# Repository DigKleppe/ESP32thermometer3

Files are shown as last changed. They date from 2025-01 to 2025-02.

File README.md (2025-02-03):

# ESP32 4 channel high resolution and accurate NTC thermometer

This project uses a dual slope approach to achive high resolution and accurate resistor measurements with a minimal nr of components.
The ADC of the ESP is not very accurate. 
An simple RC is used in combination with a internal ESP timer and a comparator to measure the RC time.
The comparater output is connected to an (high priority) interrupt input.
The process is simple: 
Charge the capacitor to VCC.
Start the timer, and discharge throuh a known reference resitor.
When the voltage level of the C is lower than the comparator reference the interrupt is fired.
The timer stops an the RC time is read.
The same steps for the NTCs.
The resistorvalues of the NTCs are proportional to the RC times.
The temperarures are calculated.

The hardware is not critical. A Filmcapacitor of 1uF and a reference resitor of 10k is used.
For optimal accuracy the value of the referency resistor must be measured and set in measureTask.h (RREF)
As comparator a LM358 is used. Maybe a real (CMOS) comparator gives even better results. If you don't need 
a very high resolution (now about 0.001 C!) you can ommit the comparator.

When measuring a fixed resistor the maximun noise is about +- 0.002 degrees C, depending of averaging.
The accuracy (-10 - 25 degrees C) is better than 0.02 degrees.
At 50 degrees (lower RC values) the deviation is 0.2 degrees. 

I use Vishay 10k 1% NTCs NTCLE203E3 103SBO.  No problem to use long wires.
To use another NTC you have to provide the parameters in NTC.h.

The nr of NTCs can be more than the 4 used here. Use IOports that don't have internal connections in the ESP.

## Website
A website is embedded to show the results in google charts.
To set the system to your network use ESP touch.

Also some settings are provided. You can set offsets to compensate for difference in NTCs. Typical 0.2 degrees max.
I use a (home made ESP) thermometer with a +- 0.1 degree accurate TMP117 sensor to calibrate.

## Project

The project is made in visual studio code. No arduino , LVGL version 9,  IDF version 5.4.

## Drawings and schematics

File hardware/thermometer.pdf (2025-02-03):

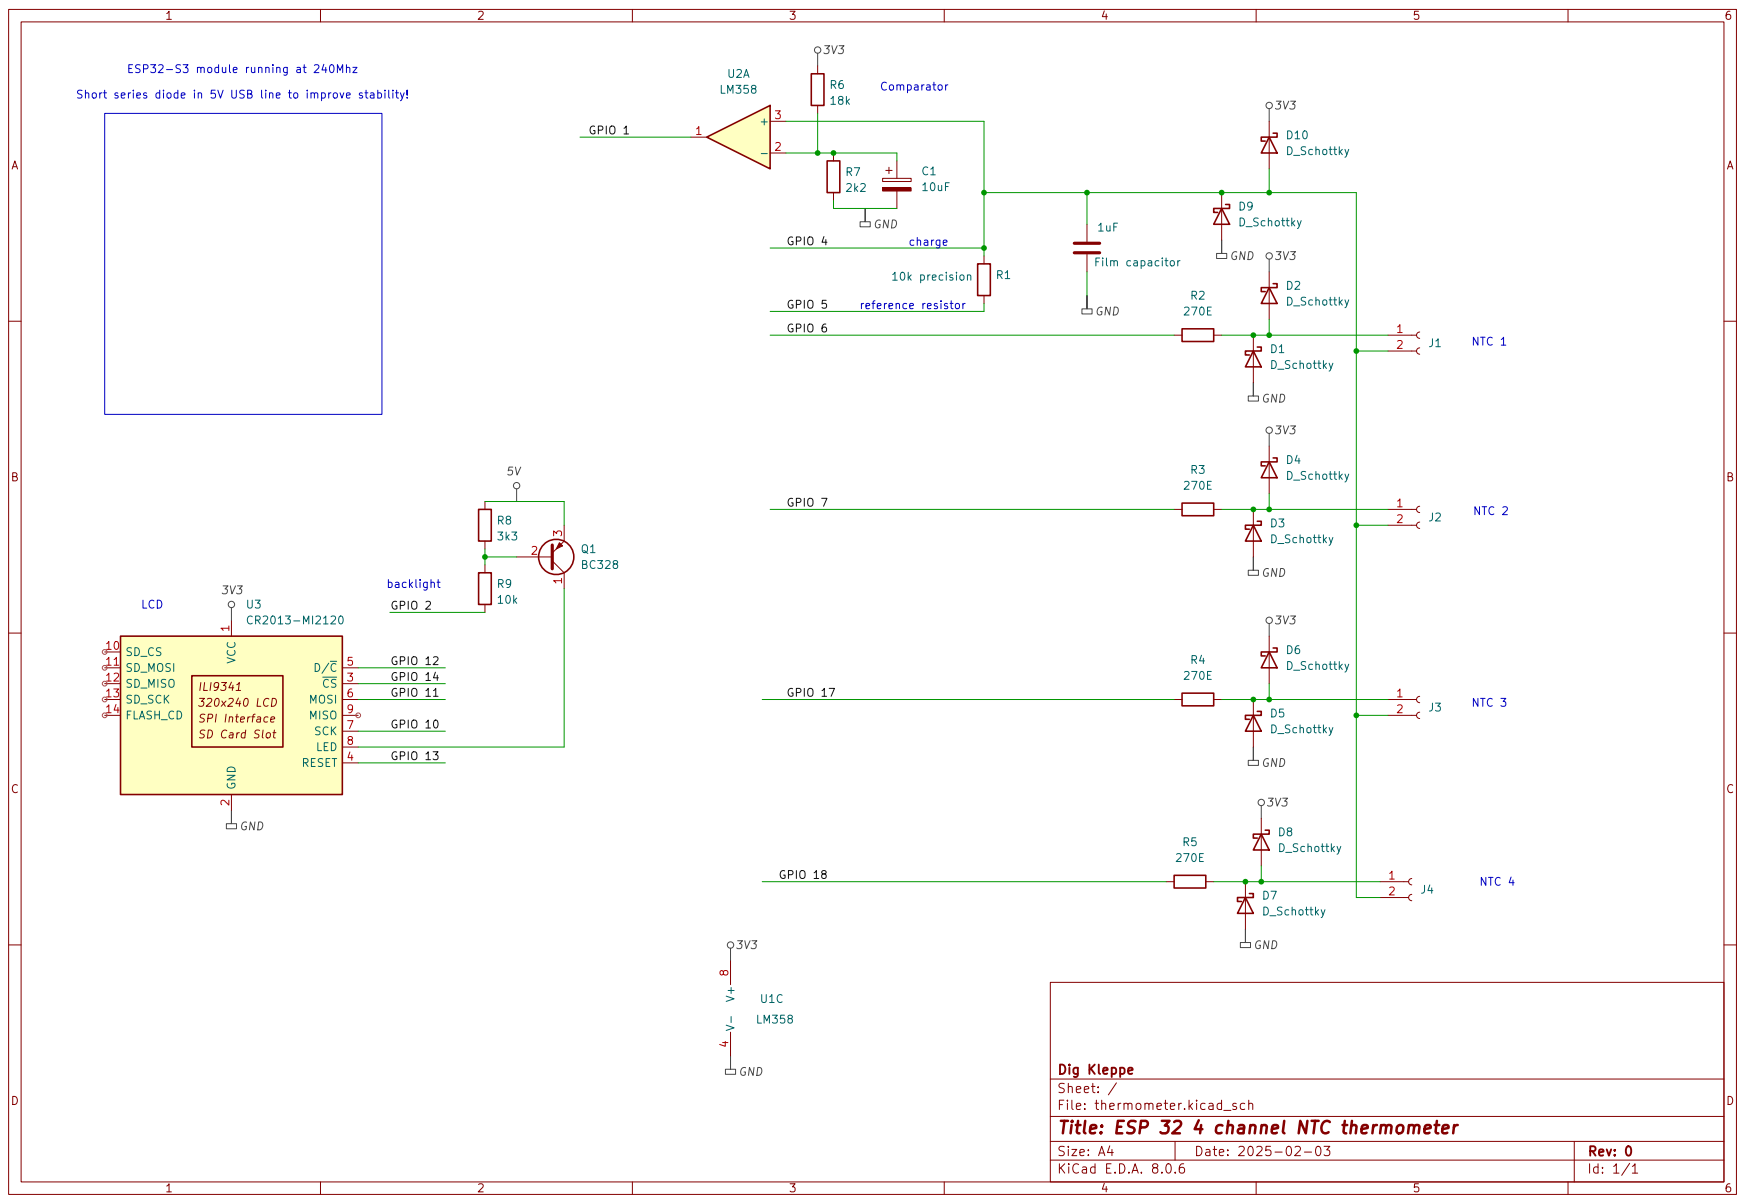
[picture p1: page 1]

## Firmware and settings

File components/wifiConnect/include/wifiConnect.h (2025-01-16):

/*
 * connect.h
 *
 *  Created on: Jan 23, 2022
 *      Author: dig
 */

#ifndef WIFI_CONNECT_H_
#define WIFI_CONNECT_H_

#include "esp_err.h"
#include "esp_netif.h"
#include "esp_wifi.h"
#include "freertos/FreeRTOS.h"
#include "freertos/task.h"
#include "sdkconfig.h"
#if CONFIG_EXAMPLE_CONNECT_ETHERNET
#include "esp_eth.h"
#endif

#ifdef __cplusplus
extern "C" {
#endif

typedef struct {
  char SSID[33];
  char pwd[64];
  esp_ip4_addr_t ip4Address;
  esp_ip4_addr_t gw;
  char upgradeURL[64];
  char upgradeFileName[32];
  bool updated;
} wifiSettings_t;

extern wifiSettings_t wifiSettings;
extern wifiSettings_t wifiSettingsDefaults;
extern char myIpAddress[];

#define STATIC_NETMASK_ADDR "255.255.255.0"
#define DEFAULT_IPADDRESS "192.168.2.50"
#define DEFAULT_GW "192.168.2.255"

extern bool DHCPoff;
extern bool DNSoff;
extern bool fileServerOff;

typedef enum {
  CONNECTING,
  CONNECTED,
  SMARTCONFIG_ACTIVE,
  IP_RECEIVED
} connectStatus_t;

extern volatile connectStatus_t connectStatus;

void wifiConnect(void);

/* Common functions for protocol examples, to establish Wi-Fi or Ethernet
   connection.

   This example code is in the Public Domain (or CC0 licensed, at your option.)

   Unless required by applicable law or agreed to in writing, this
   software is distributed on an "AS IS" BASIS, WITHOUT WARRANTIES OR
   CONDITIONS OF ANY KIND, either express or implied.
 */

// protocol examples common.h

#if !CONFIG_IDF_TARGET_LINUX
#if CONFIG_EXAMPLE_CONNECT_WIFI
#define EXAMPLE_NETIF_DESC_STA "netif_sta"
#endif

#if CONFIG_EXAMPLE_CONNECT_ETHERNET
#define EXAMPLE_NETIF_DESC_ETH "netif_eth"
#endif

/* Example default interface, prefer the ethernet one if running in example-test
 * (CI) configuration */
#if CONFIG_EXAMPLE_CONNECT_ETHERNET
#define EXAMPLE_INTERFACE get_netif_from_desc(EXAMPLE_NETIF_DESC_ETH)
#define get_netif() get_netif_from_desc(EXAMPLE_NETIF_DESC_ETH)
#elif CONFIG_EXAMPLE_CONNECT_WIFI
#define EXAMPLE_INTERFACE get_netif_from_desc(EXAMPLE_NETIF_DESC_STA)
#define get_netif() get_netif_from_desc(EXAMPLE_NETIF_DESC_STA)
#endif

/**
 * @brief Configure Wi-Fi or Ethernet, connect, wait for IP
 *
 * This all-in-one helper function is used in protocols examples to
 * reduce the amount of boilerplate in the example.
 *
 * It is not intended to be used in real world applications.
 * See examples under examples/wifi/getting_started/ and examples/ethernet/
 * for more complete Wi-Fi or Ethernet initialization code.
 *
 * Read "Establishing Wi-Fi or Ethernet Connection" section in
 * examples/protocols/README.md for more information about this function.
 *
 * @return ESP_OK on successful connection
 */
// esp_err_t connect(void);

/**
 * Counterpart to connect, de-initializes Wi-Fi or Ethernet
 */
esp_err_t disconnect(void);

/**
 * @brief Configure stdin and stdout to use blocking I/O
 *
 * This helper function is used in ASIO examples. It wraps installing the
 * UART driver and configuring VFS layer to use UART driver for console I/O.
 */
esp_err_t configure_stdin_stdout(void);

/**
 * @brief Returns esp-netif pointer created by connect() described by
 * the supplied desc field
 *
 * @param desc Textual interface of created network interface, for example "sta"
 * indicate default WiFi station, "eth" default Ethernet interface.
 *
 */
esp_netif_t *get_netif_from_desc(const char *desc);

#if CONFIG_EXAMPLE_PROVIDE_WIFI_CONSOLE_CMD
/**
 * @brief Register wifi connect commands
 *
 * Provide a simple wifi_connect command in esp_console.
 * This function can be used after esp_console is initialized.
 */
void register_wifi_connect_commands(void);
#endif

#if CONFIG_EXAMPLE_CONNECT_ETHERNET
/**
 * @brief Get the example Ethernet driver handle
 *
 * @return esp_eth_handle_t
 */
esp_eth_handle_t get_eth_handle(void);
#endif // CONFIG_EXAMPLE_CONNECT_ETHERNET

#else
static inline esp_err_t connect(void) { return ESP_OK; }
#endif // !CONFIG_IDF_TARGET_LINUX

#define CONFIG_EXAMPLE_WIFI_CONN_MAX_RETRY 10

#if CONFIG_EXAMPLE_CONNECT_IPV6
#define MAX_IP6_ADDRS_PER_NETIF (5)

#if defined(CONFIG_EXAMPLE_CONNECT_IPV6_PREF_LOCAL_LINK)
#define EXAMPLE_CONNECT_PREFERRED_IPV6_TYPE ESP_IP6_ADDR_IS_LINK_LOCAL
#elif defined(CONFIG_EXAMPLE_CONNECT_IPV6_PREF_GLOBAL)
#define EXAMPLE_CONNECT_PREFERRED_IPV6_TYPE ESP_IP6_ADDR_IS_GLOBAL
#elif defined(CONFIG_EXAMPLE_CONNECT_IPV6_PREF_SITE_LOCAL)
#define EXAMPLE_CONNECT_PREFERRED_IPV6_TYPE ESP_IP6_ADDR_IS_SITE_LOCAL
#elif defined(CONFIG_EXAMPLE_CONNECT_IPV6_PREF_UNIQUE_LOCAL)
#define EXAMPLE_CONNECT_PREFERRED_IPV6_TYPE ESP_IP6_ADDR_IS_UNIQUE_LOCAL
#endif // if-elif CONFIG_EXAMPLE_CONNECT_IPV6_PREF_...

#endif

#if CONFIG_EXAMPLE_CONNECT_IPV6
extern const char *ipv6_addr_types_to_str[6];
#endif

void wifi_start(void);
void wifi_stop(void);
esp_err_t wifi_sta_do_connect(wifi_config_t wifi_config, bool wait);
esp_err_t wifi_sta_do_disconnect(void);
bool is_our_netif(const char *prefix, esp_netif_t *netif);
void print_all_netif_ips(const char *prefix);
void wifi_shutdown(void);
esp_err_t wifi_connect(void);
void ethernet_shutdown(void);
esp_err_t ethernet_connect(void);

#ifdef __cplusplus
}
#endif

#endif /* WIFI_CONNECT_H_ */

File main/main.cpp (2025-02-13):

#include <stdbool.h>
#include <stdio.h>
#include <stdlib.h>
#include <string.h>

#include "esp_freertos_hooks.h"
#include "freertos/FreeRTOS.h"
#include "freertos/task.h"

#include "driver/gpio.h"
#include "esp_http_client.h"
#include "esp_log.h"
#include "esp_sleep.h"
#include "esp_system.h"
#include "esp_wifi.h"

#include "esp_event.h"
#include "esp_netif.h"
#include "nvs_flash.h"

#include "LCD.h"
#include "guiTask.h"
#include "mdns.h"
#include "settings.h"
#include "spiffs.h"
#include "wifiConnect.h"

#include <stdbool.h>
#include <stdio.h>
#include <stdlib.h>
#include <string.h>

static const char *TAG = "main";

#define MAXSTRLEN 80
const gpio_num_t LED_PIN = GPIO_NUM_9;

uint32_t timeStamp;

void vTimerCallback(TimerHandle_t xTimer)
{
	timeStamp++;
}

extern "C"
{
	void app_main()
	{
		esp_err_t err;
		displayMssg_t displayMssg;
		uint32_t upTime = 0;
		bool toggle = false;
		TimerHandle_t xTimer;

		gpio_set_direction(LED_PIN, GPIO_MODE_OUTPUT);
		gpio_set_level(LED_PIN, 0);

		ESP_ERROR_CHECK(esp_event_loop_create_default());

		ESP_LOGI(TAG, "\n **************** start *****************\n");

		err = nvs_flash_init();
		if (err == ESP_ERR_NVS_NO_FREE_PAGES || err == ESP_ERR_NVS_NEW_VERSION_FOUND)
		{
			ESP_ERROR_CHECK(nvs_flash_erase());
			err = nvs_flash_init();
			ESP_LOGI(TAG, "nvs flash erased");
		}
		ESP_ERROR_CHECK(err);

		ESP_ERROR_CHECK(init_spiffs());

		err = loadSettings();
		ESP_LOGI(TAG, "connecting to %s", wifiSettings.SSID);

		xTimer = xTimerCreate("Timer", 10, pdTRUE, (void *)0, vTimerCallback);
		xTimerStart(xTimer, 0);

		vTaskDelay(500 / portTICK_PERIOD_MS);
		xTaskCreate(&guiTask, "guiTask", 1024 * 8, NULL, 0, NULL);
		xTaskCreatePinnedToCore(&measureTask, "measureTask", 3500, NULL, 2, NULL, 1);
		//		wifiConnect();

		displayMssg.line = 5;
		displayMssg.showTime = 0;

		while (1)
		{
			vTaskDelay(1000 / portTICK_PERIOD_MS);
			upTime++;
			if (settingsChanged)
			{
				settingsChanged = false;
				setBacklight(userSettings.backLight);
				saveSettings();
			}
			if ((connectStatus != IP_RECEIVED))
			{
				toggle = !toggle;
				gpio_set_level(LED_PIN, toggle);

				displayMssg.text = (char *)malloc(MAXSTRLEN);
				if (displayMssg.text == NULL)
					ESP_LOGE(TAG, "malloc failed");
				else
				{
					snprintf(displayMssg.text, MAXSTRLEN, "Verbinden met %s", wifiSettings.SSID);
					xQueueSend(displayMssgBox, &displayMssg, portMAX_DELAY);
				}
			}
			else
			{
				gpio_set_level(LED_PIN, false);

				if (wifiSettings.updated)
				{
					wifiSettings.updated = false;
					saveSettings();
				}
				displayMssg.text = (char *)malloc(MAXSTRLEN);
				if (displayMssg.text == NULL)
					ESP_LOGE(TAG, "malloc failed");
				else
				{
					snprintf(displayMssg.text, MAXSTRLEN, "%s  %s  %s", wifiSettings.SSID, myIpAddress, userSettings.moduleName);

					xQueueSend(displayMssgBox, &displayMssg, portMAX_DELAY);
				}
			}
		}
	}
}

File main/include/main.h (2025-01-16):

/*
 * main.h
 *
 *  Created on: Sep 9, 2019
 *      Author: dig
 */

#ifndef MAIN_INCLUDE_MAIN_H_
#define MAIN_INCLUDE_MAIN_H_

// #define DMMBOARD				1

#ifdef DMMBOARD

#define RREF 100680 // in ohms
#define CAP_PIN GPIO_NUM_16
#define RREF_PIN GPIO_NUM_18
#define NTC1_PIN GPIO_NUM_23
#define NTC2_PIN GPIO_NUM_19
#define NTC3_PIN GPIO_NUM_18
#define NTC4_PIN RREF_PIN

#define CONFIG_CLK 18          // pin 12 J8
#define CONFIG_MISO 19         // pin 14
#define CONFIG_MOSI 23         // pin 16
#define CONFIG_NSS 32          // relay
#define CONFIG_RST 16          // tp17
#define CONFIG_DIO0 GPIO_NUM_4 // tp18
// io 25 and 26 used for HX711 scale, connected to pin 7 / 8 J8 extension
// connector

#define OLED_SDA 21
#define OLED_SCL 22

#define TP_SDA GPIO_NUM_21
#define TP_SCL GPIO_NUM_22

#else

#define SDA_PIN 4
#define SCL_PIN 2

#define LED_PIN GPIO_NUM_42

// #define TP_1			GPIO_NUM_12
// #define TP_2			GPIO_NUM_13

#endif

#define I2C_MASTER_SCL_IO SCL_PIN   /*!< gpio number for I2C master clock */
#define I2C_MASTER_SDA_IO SDA_PIN   /*!< gpio number for I2C master data  */
#define I2C_MASTER_NUM I2C_NUM_1    /*!< I2C port number for master dev */
#define I2C_MASTER_TX_BUF_DISABLE 0 /*!< I2C master do not need buffer */
#define I2C_MASTER_RX_BUF_DISABLE 0 /*!< I2C master do not need buffer */
#define I2C_MASTER_FREQ_HZ 400000   /*!< I2C master clock frequency */

#endif /* MAIN_INCLUDE_MAIN_H_ */

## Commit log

2025-01-03 pinning sheet changed
    [ESP32pinning.ods]
2025-01-05 pinning changed
    [ESP32pinning.ods]
2025-02-02 IRQ only stops timer, works perfect now
2025-02-03 added hardware
    [thermometer.kicad_sch]
2025-02-13 tested only reference resistor
2025-02-13 ods changed
    [NTC.ods]
